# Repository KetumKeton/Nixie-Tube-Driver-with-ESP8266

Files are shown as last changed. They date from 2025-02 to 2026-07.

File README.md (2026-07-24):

<div align="right">
  <a href="README.en.md">🇬🇧 English</a> |
  <a href="README.md">🇹🇷 Türkçe</a>
</div>

# 🔥 Nixie Tube Driver with ESP8266

Wi-Fi bağlantılı, ESP8266 tabanlı Nixie tüp sürücü kartı. Nixie saat ve sayısal gösterge projeleri için tasarlanmıştır; interneti kullanarak saatini otomatik kalibre eder ve zaman bölmeli çoklama (time-division multiplexing) ile birden fazla tüpü aynı anda sürer.

<p align="center">
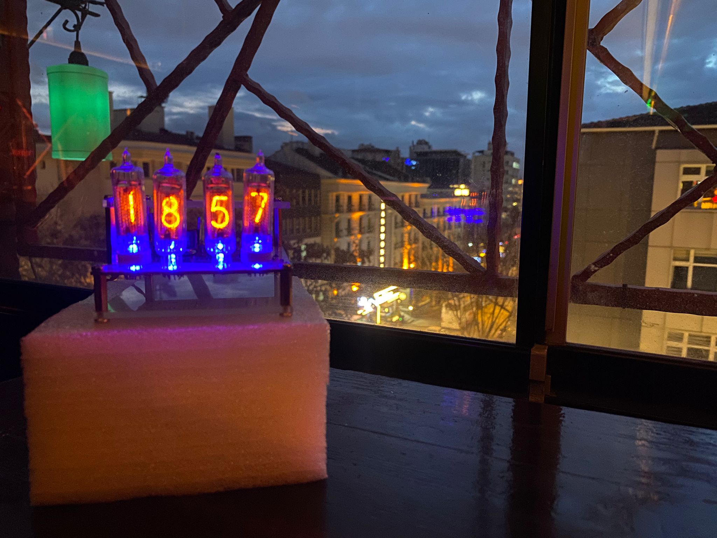
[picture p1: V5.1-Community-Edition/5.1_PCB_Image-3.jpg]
V5.2 Image
  
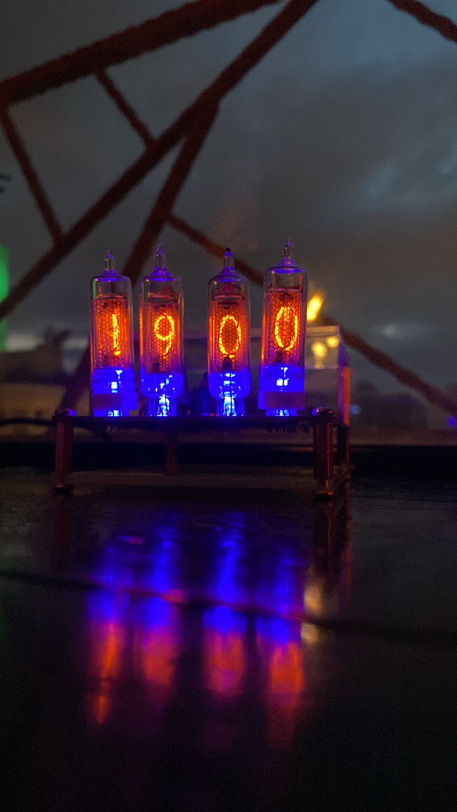
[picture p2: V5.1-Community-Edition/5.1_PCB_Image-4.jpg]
V5.2 Image
  
</p>
<p align="center">
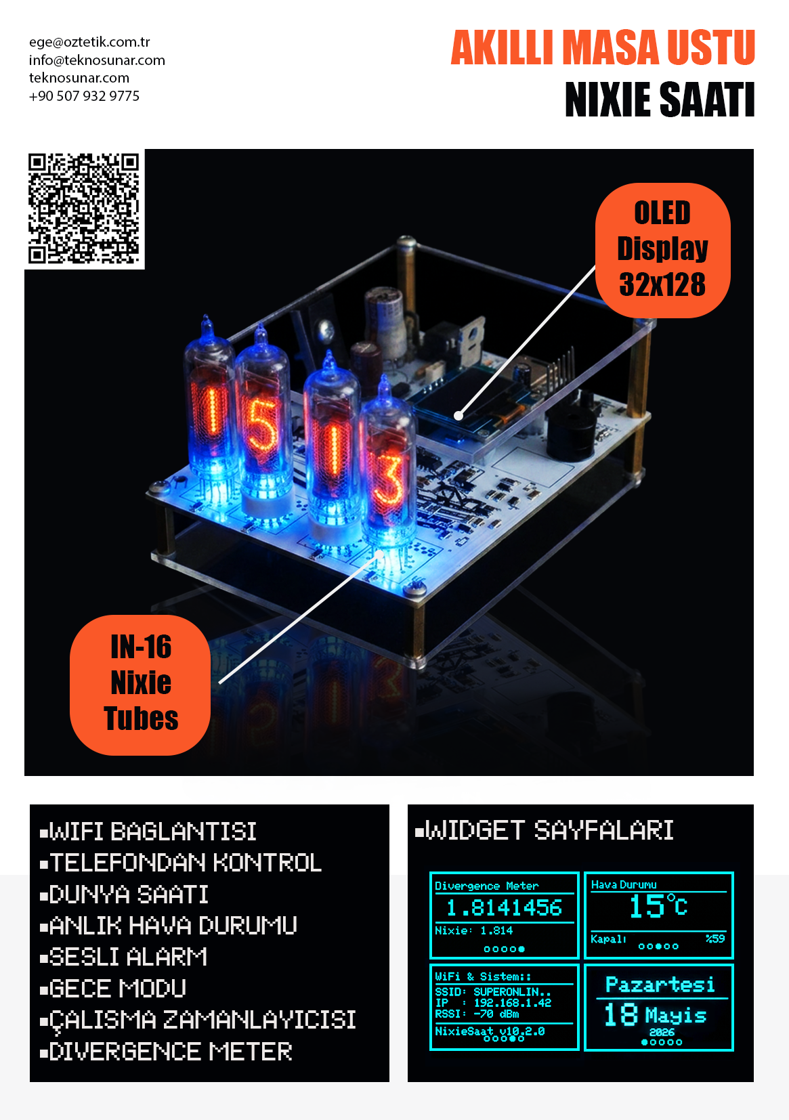
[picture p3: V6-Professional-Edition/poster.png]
    
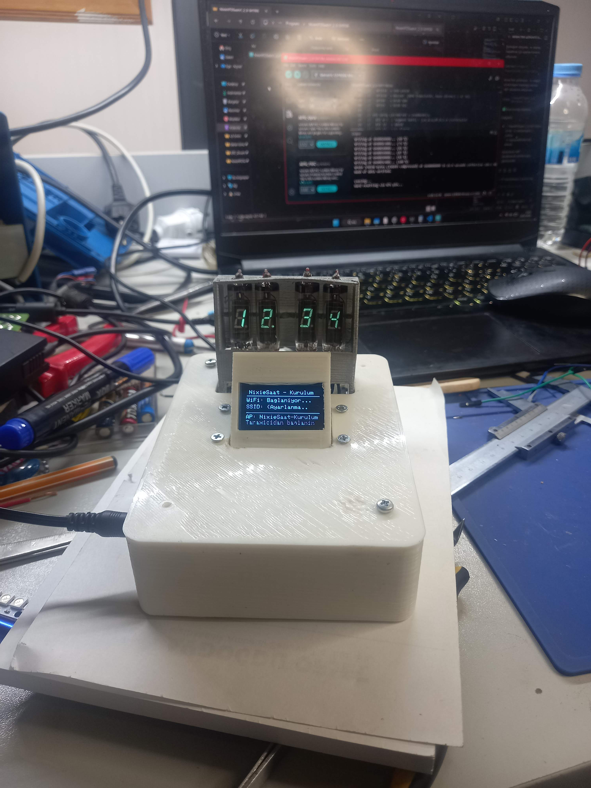
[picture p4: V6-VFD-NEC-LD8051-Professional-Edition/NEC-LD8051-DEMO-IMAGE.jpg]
V6-VFD Image
  
</p>
---

## 📖 İçindekiler

- [Proje Hakkında](#-proje-hakkında)
- [Özellikler](#-özellikler)
- [Donanım Gereksinimleri](#-donanım-gereksinimleri)
- [Kurulum ve Kullanım](#-kurulum-ve-kullanım)
- [Galeri](#-galeri)
- [Versiyon Notları](#-versiyon-notları)
- [Yol Haritası](#-yol-haritası)
- [Lisans](#-lisans)
- [Katkıda Bulunma](#-katkıda-bulunma)

---

## 🧭 Proje Hakkında

Bu proje, Nixie tüplerini (IN-16 için tasarlanmıştır, IN-12/IN-14/IN-18 gibi diğer tüplerle de uyumludur / Pro versiyonunda NEC-8051 / IV-3 VFD tüplerine uygun tasarımda bulunmaktadır) sürmek için gereken yüksek gerilim anahtarlama devresini, mikrodenetleyici firmware'ini ve PCB tasarımını bir arada sunar. Kart, ESP8266 üzerinden internete bağlanarak NTP ile saatini otomatik senkronize eder, böylece harici bir RTC pil değişimine veya manuel saat ayarına gerek kalmaz.

### Open Core - Community Edition
Açık kaynak felsefesine inandığım için, bu Nixie saatin temel versiyonunu herkesin kendi evinde yapabilmesi adına şemaları, kodları ve CAM dosyalarıyla v5.1 Comunity Edition olarak paylaşıyorum. Eğer kendi ESP8266'nızı programlamak, shift register'larla uğraşmak ve 170V DC-DC boost konvertör gibi yüksek voltajlı devreleri kendi başınıza kurmak istiyorsanız, ihtiyacınız olan her şey bu depoda mevcut!"

### Proffesional Edition
"Ancak, lehim yapmakla, parça tedarikiyle veya yüksek voltajla uğraşmak istemiyorsanız; çok daha gelişmiş bir web arayüzüne, ekstra animasyon modlarına ve kusursuz bir tasarıma sahip olan tam donanımlı versiyonu doğrudan tak-çalıştır bir ürün olarak satın almak isterseniz aşşağıdaki iletişim adresinden bana ulaşabilirsiniz.

Web Site: teknosunar.com / oztetik.com.tr
mail: info@teknosunar.com / ege@oztetik.com.tr
github: KetumKeton
linkedin: ege-oztetik

## ✨ Özellikler

**Donanım**
- 🔥 IN-16 Nixie tüpleri için optimize edilmiş sürücü devresi; diğer Nixie tipleriyle de uyumlu
- 🔄 4 tüpün aynı anda, zaman bölmeli çoklama (16 transistörlü anahtarlama) ile sürülmesi
- ⚡ Dahili MC34063 DC-DC çevirici ile 150V DC yüksek gerilim üretimi (harici trafoya gerek yok — V5 ve sonrası)
- 🔋 Düşük güç tüketimine göre optimize edilmiş anahtarlama tasarımı
- 🎨 Estetik odaklı, sıkı yerleşimli PCB tasarımı (80×100 mm, V5)
- 🖥️ İsteğe bağlı OLED ekran bağlantısı (alternatif/yardımcı çıkış)
- 🟦 Nixie tüpleri için mavi arka plan LED desteği

**Yazılım / Firmware**
- 📶 ESP8266 üzerinden otomatik Wi-Fi bağlantısı
- 🕒 İnternet üzerinden NTP ile gerçek zamanlı saat kalibrasyonu
- 💡 Ayarlanabilir parlaklık ve yumuşak geçiş/söndürme (fade) efektleri
- 🔌 Seri haberleşme desteği (test ve yapılandırma için)
- 🧩 CD4094 kaydırma yazmaçları üzerinden basamak sürme

## 🛠 Donanım Gereksinimleri

| Bileşen | Not |
|---|---|
| Mikrodenetleyici | ESP8266 (ESP-12) |
| Nixie Tüpleri | IN-16 için tasarlandı (IN-12, IN-14, IN-18 ile de uyumlu) |
| Yüksek Gerilim Kaynağı | 150V DC (V5'te kart üzerinde MC34063 ile üretilir) |
| Sürücü IC | CD4094 (kaydırma yazmacı), ULN2003 (küçük SMD versiyonda) |

## 🚀 Kurulum ve Kullanım

1. **Depoyu klonlayın**
   ```sh
   git clone https://github.com/Ketonkeko/Nixie-Tube-Driver-with-ESP8266.git
   cd Nixie-Tube-Driver-with-ESP8266
   ```

2. **Gerber dosyalarını üretim için alın**
   - İlgili versiyon klasöründeki zip dosyasını açın; içinden drill ve copper Gerber dosyalarını çıkarıp PCB üreticinize gönderin.

3. **Firmware'i yükleyin**
   - İlgili versiyon klasöründeki Arduino/ESP8266 projesini açın.
   - Wi-Fi ağı bilgilerinizi kod içinde ilgili değişkenlere girin.
   - Kartı USB-seri dönüştürücü ile bağlayıp firmware'i ESP8266'ya yükleyin.

4. **İlk çalıştırma**
   - Kart açıldığında tanımlı Wi-Fi ağına bağlanır ve NTP sunucusundan saati çeker.
   - Yüksek gerilim beslemesini (150V) ve tüp soketlerini bağlamadan önce devrenin güç kesici olduğundan emin olun.

> ⚠️ **Güvenlik uyarısı:** Bu kart 150V DC gibi tehlikeli seviyede yüksek gerilimle çalışır. Kartı yalnızca yüksek gerilim devreleriyle çalışma tecrübeniz varsa enerjilendirin.

## 🖼 Galeri

<table>
  <tr>
    <td align="center">
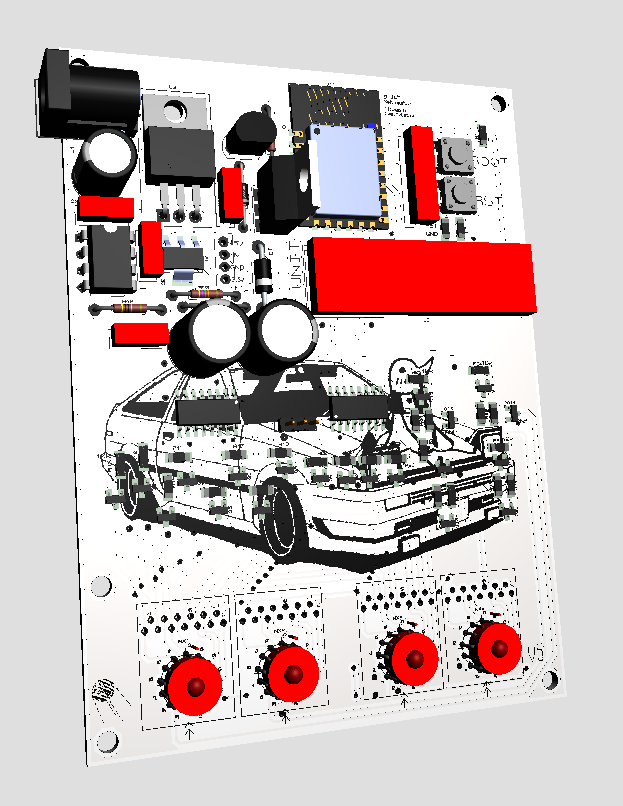
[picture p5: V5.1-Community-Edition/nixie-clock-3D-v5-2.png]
V5.2 3D Görünüm
      <br>
      <sub>V5.2 — 3D model</sub>
    </td>
    <td align="center">
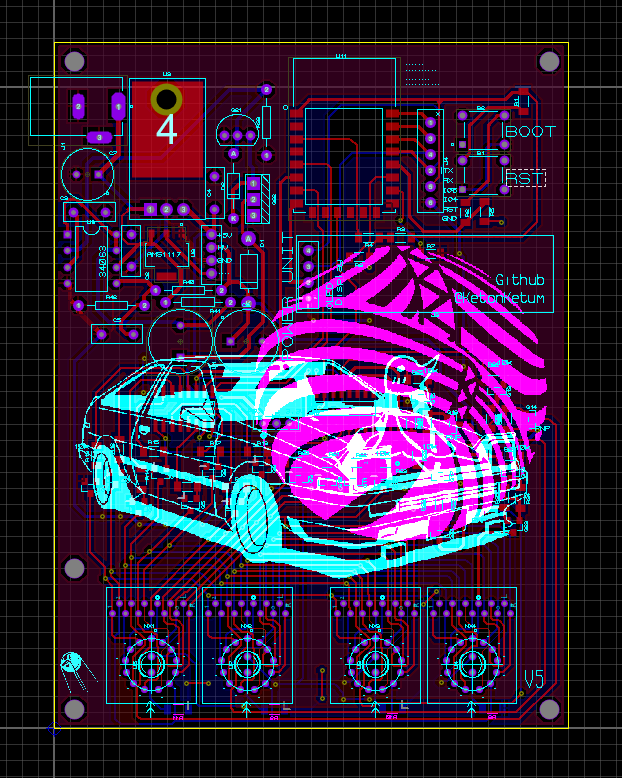
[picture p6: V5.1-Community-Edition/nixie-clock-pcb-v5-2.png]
V5.2 PCB Görünümü
      <br>
      <sub>V5.2 — PCB düzeni</sub>
    </td>
  </tr>
  <tr>
    <td align="center">
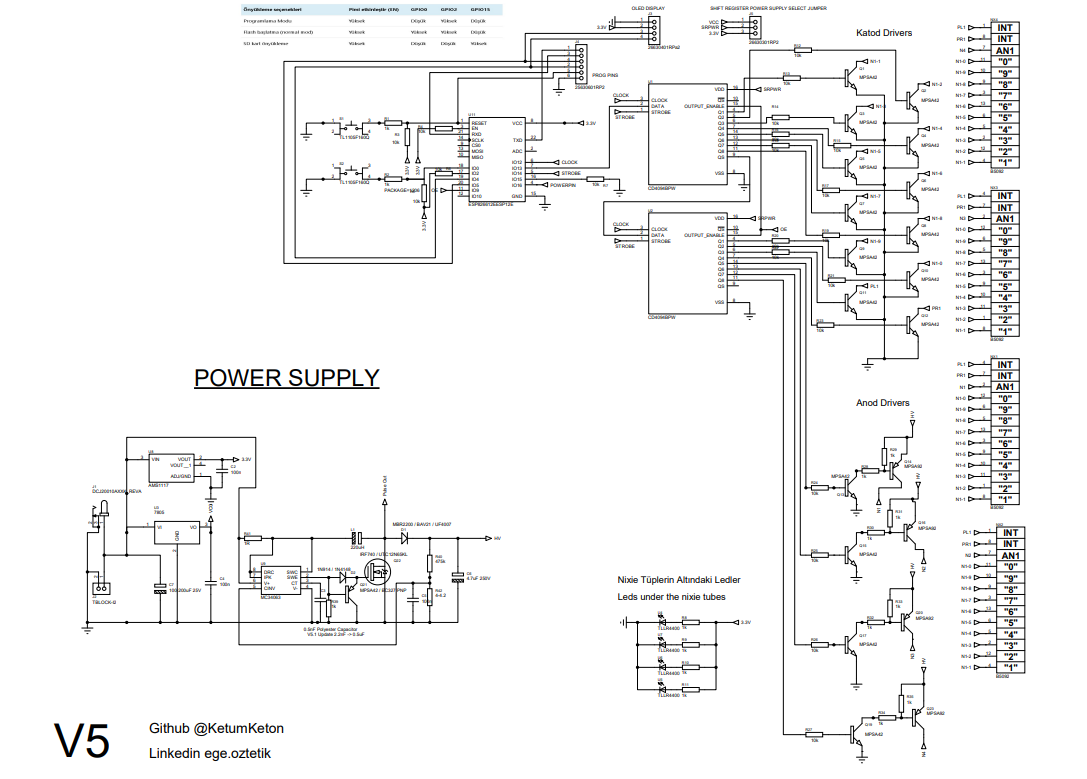
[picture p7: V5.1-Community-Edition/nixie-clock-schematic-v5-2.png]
V5.2 Şematik
      <br>
      <sub>V5.2 — Şematik</sub>
    </td>
    <td align="center">
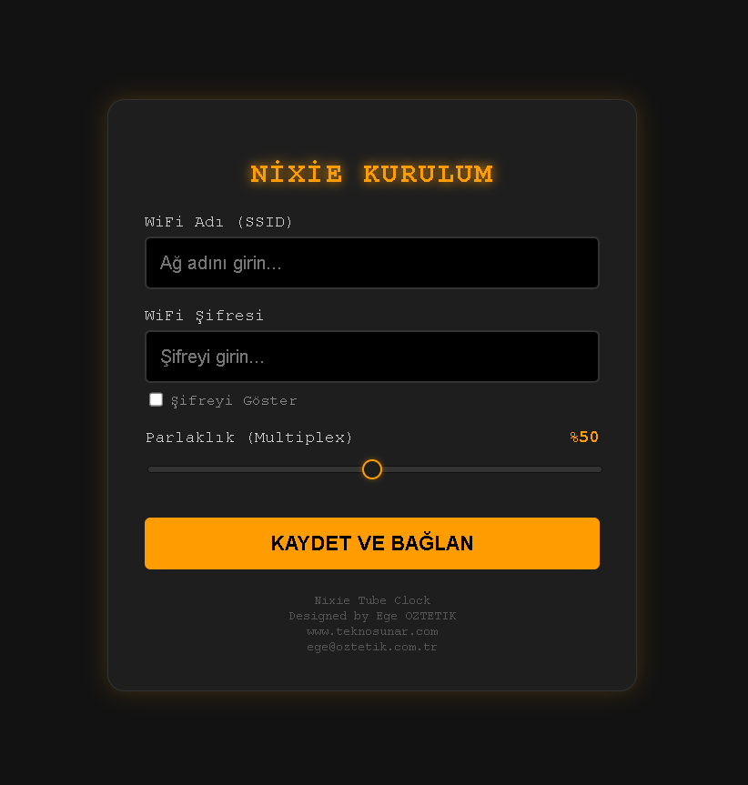
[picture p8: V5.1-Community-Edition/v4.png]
V4 Uygulama Görseli
      <br>
      <sub>V4 — Örnek uygulama</sub>
    </td>
  </tr>
  <tr>
    <td align="center">
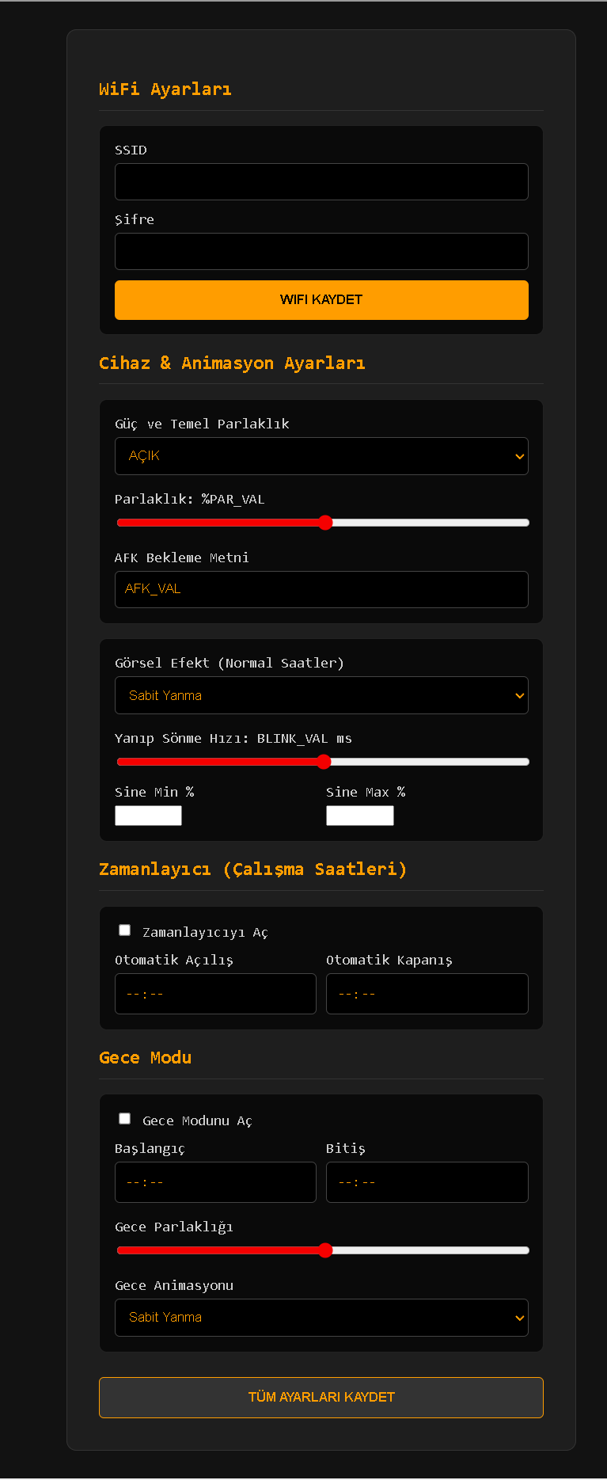
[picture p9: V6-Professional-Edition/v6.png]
V6 Uygulama Görseli
      <br>
      <sub>V6 — Örnek uygulama</sub>
    </td>
    <td align="center">
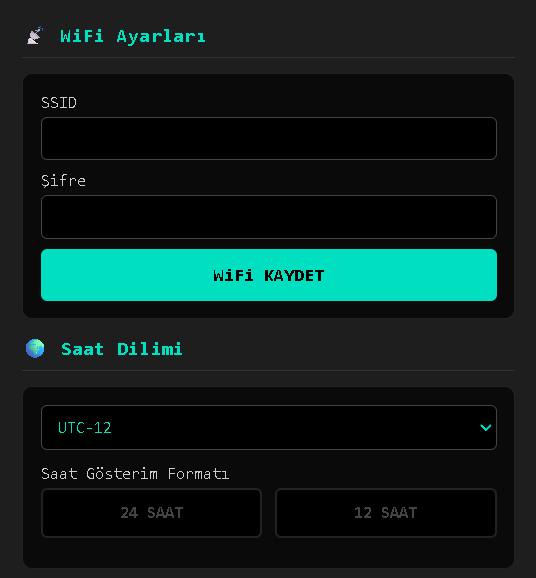
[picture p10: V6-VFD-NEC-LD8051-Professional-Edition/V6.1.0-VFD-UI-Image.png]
V6 VFD Test
      <br>
      <sub>V6 — NEC LD8051 VFD test</sub>
    </td>
  </tr>
    <tr>
    <td align="center">
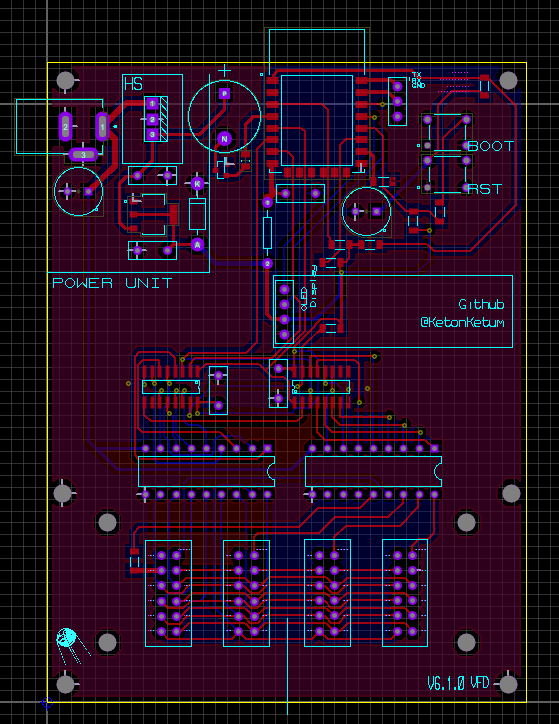
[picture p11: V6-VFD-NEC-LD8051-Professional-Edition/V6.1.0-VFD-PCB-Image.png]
      <br>
      <sub>V6 — Örnek uygulama</sub>
    </td>
    <td align="center">
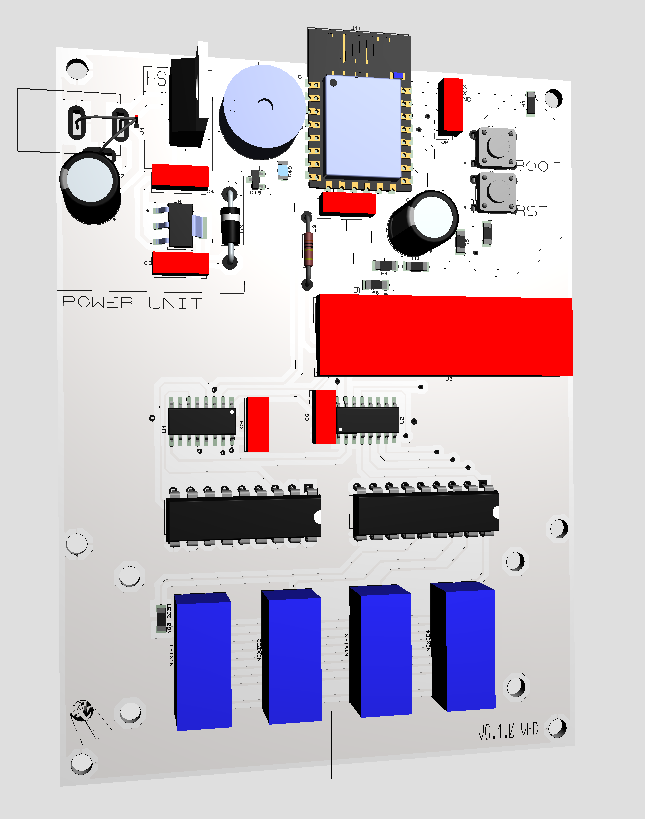
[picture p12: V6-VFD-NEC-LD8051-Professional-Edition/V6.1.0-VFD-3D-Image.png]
      <br>
      <sub>V6 — NEC LD8051 VFD test</sub>
    </td>
  </tr>
    <tr>
    <td align="center">
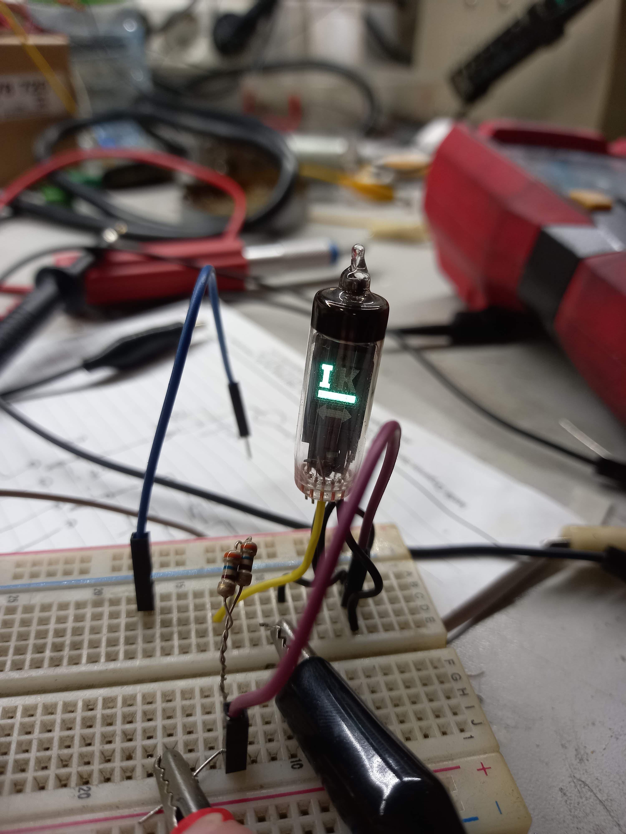
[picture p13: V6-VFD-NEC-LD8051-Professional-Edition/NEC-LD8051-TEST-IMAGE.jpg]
      <br>
      <sub>V6 — Örnek uygulama</sub>
    </td>
    <td align="center">
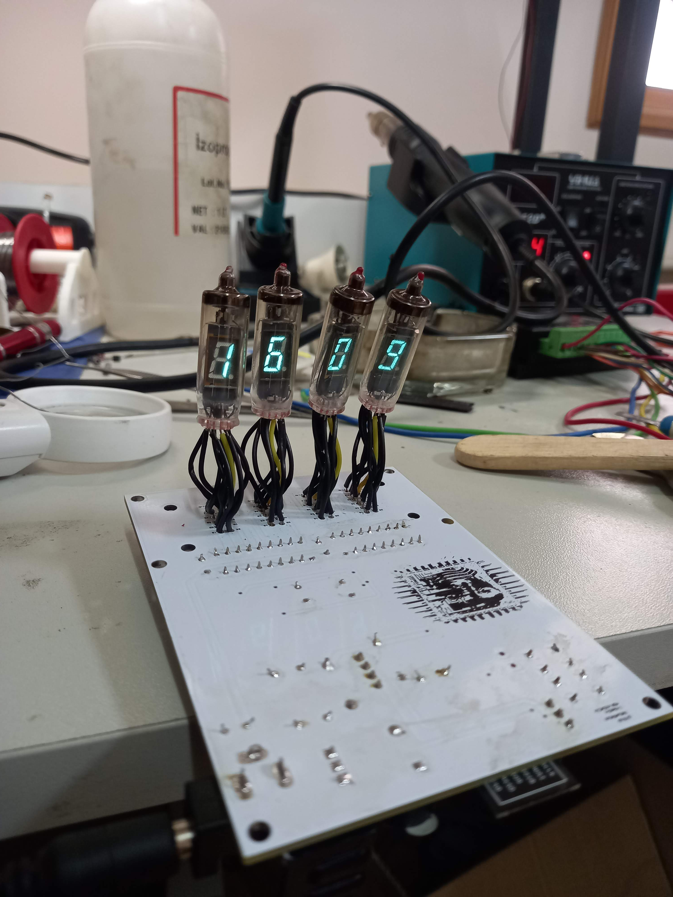
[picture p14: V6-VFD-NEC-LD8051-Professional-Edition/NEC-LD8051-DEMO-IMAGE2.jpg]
      <br>
      <sub>V6 — NEC LD8051 VFD test</sub>
    </td>
  </tr>
</table>

## 🗂 Versiyon Notları

### V6 — VFD Desteği
- NEC LD8051 VFD (vakum floresan gösterge) ile deneysel test desteği eklendi.
- UI VFD Tüplere Göre Güncellendi
- Dış Kasa Tasarlandı (oled ve VFD tüleri için soket tasarımı dahil)
- Kontrol Şeması 7 segment olucak şekilde yeniden yazıldı ve program güncellendi

### V6 Notları
- Program Güncellemeleri Yapıldı ve Yeni Özellikler Eklendi v10-3 (Alarm, Çalışma Zamanlayıcısı, Gece Modu, Effektler, Yakınsama Sayısı Modu, Saat Gösterim Şekilleri ve Yerel Zaman Seçenekleri vs)
- Koruma Elemanları ve Bleeder direnci Eklendi 
- Tasarım Değişiklikleri Yapıldı ve Çalışma daha Stabil Hale getirildi
- Tüplerin Çalışma Ömrünü uzatmak amacıyla Katot koruması vb koruma özellikleri eklendi

### V5 Notları
- Harici trafo yerine dahili MC34063 DC-DC çeviricisi entegre edildi.
- Anot sürücüsündeki hata giderildi.
- Güç filtrelemesi için ek kapasitörler eklendi.
- Güç girişlerine dahili diyotlar eklendi.
- PCB, 80×100 mm ölçüsünde yeniden çizildi.
- CD4094, SO16 paketine geçirildi.
- Bazı hatlar kalınlaştırıldı.
- Pin header boyutları güncellendi.
- 402 paket kapasitörler 603'e dönüştürüldü.
- OLED ekran daha görünür bir konuma taşındı.
- Nixie mavi LED dirençleri 1206 pakete dönüştürüldü.
- Nixie tüp soket boyutu güncellendi.

### V4 Notları
- Mikrodenetleyici AT89C4051'den ESP8266'ya değiştirildi.
- RS485 haberleşmesi kaldırılıp Wi-Fi eklendi.
- 16 transistörlü zaman bölmeli çoklama ile 4 tüpün eşzamanlı sürülmesi sağlandı.
- Daha iyi PCB tasarımı için bitmap desteği eklendi.
- Üretim ve boyut iyileştirmesi için paket DIP'ten SMD'ye değiştirildi.
- HV ve 12V girişleri harici güç kaynağına (trafo) bağlandı.
- Alternatif çıkış seçeneği olarak OLED ekran pinleri eklendi.

## 🗺 Yol Haritası

- [x] ESP8266 E-12 ile saat programının yazılması
- [x] SMD ve ULN2003 IC ile daha küçük PCB tasarımı
- [x] Saat için 3D kasa tasarımı
- [x] PCB ve program testleri
- [x] Parça listesi ve maliyet hesaplaması
- [X] ESP8266 üzerinde yerel sunucu ile alarm ve saat dilimi ayarı
- [X] UI İyileştirmeleri
- [ ] Çeşitli Dış Kasa Tasarımları Yapılıcak
- [ ] RTC Eklenecek
- [ ] 6 Tüplü Versiyon Tasarlanacak
- [ ] Pleksi-Ledli Versiyon Tasarlanacak

## 📜 Lisans

Bu proje **MIT Lisansı** ile lisanslanmıştır. Ayrıntılar için [LICENSE](LICENSE) dosyasına bakın.

## 🤝 Katkıda Bulunma

Katkılarınızı bekliyoruz! **Pull request** gönderebilir veya **issue** açabilirsiniz.

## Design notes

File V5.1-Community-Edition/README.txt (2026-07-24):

# Open-Core - Community Edition
Açık kaynak felsefesine inandığım için, bu Nixie saatin temel versiyonunu herkesin kendi evinde yapabilmesi adına şemaları, kodları ve CAM dosyalarıyla v5.1 Community Edition olarak paylaşıyorum. Eğer kendi ESP8266'nızı programlamak, shift register'larla uğraşmak ve 170V DC-DC boost konvertör gibi yüksek voltajlı devreleri kendi başınıza kurmak istiyorsanız, ihtiyacınız olan her şey bu depoda mevcut!

# Professional Edition
Ancak, lehim yapmakla, parça tedarikiyle veya yüksek voltajla uğraşmak istemiyorsanız; çok daha gelişmiş bir web arayüzüne, ekstra animasyon modlarına ve kusursuz bir tasarıma sahip olan tam donanımlı versiyonu doğrudan tak-çalıştır bir ürün olarak satın almak isterseniz aşağıdaki iletişim adreslerinden bana ulaşabilirsiniz.

Web Site: teknosunar.com / oztetik.com.tr
mail: info@teknosunar.com / ege@oztetik.com.tr
github: KetumKeton
linkedin: ege-oztetik

# Open-Core - Community Edition
As a believer in the open-source philosophy, I am sharing the schematics, source codes, and CAM files of this Nixie clock's basic version as the v5.1 Community Edition, so anyone can build it at home. If you want to program your own ESP8266, tinker with shift registers, and build high-voltage circuits like a 170V DC-DC boost converter yourself, everything you need is right here in this repository!

# Professional Edition
However, if you'd rather not deal with soldering, sourcing components, or handling high voltages; and would prefer a fully equipped, plug-and-play product featuring a much more advanced web interface, extra animation modes, and a flawless design, you can contact me via the channels below to purchase one.

Web Site: teknosunar.com / oztetik.com.tr
mail: info@teknosunar.com / ege@oztetik.com.tr
github: KetumKeton
linkedin: ege-oztetik

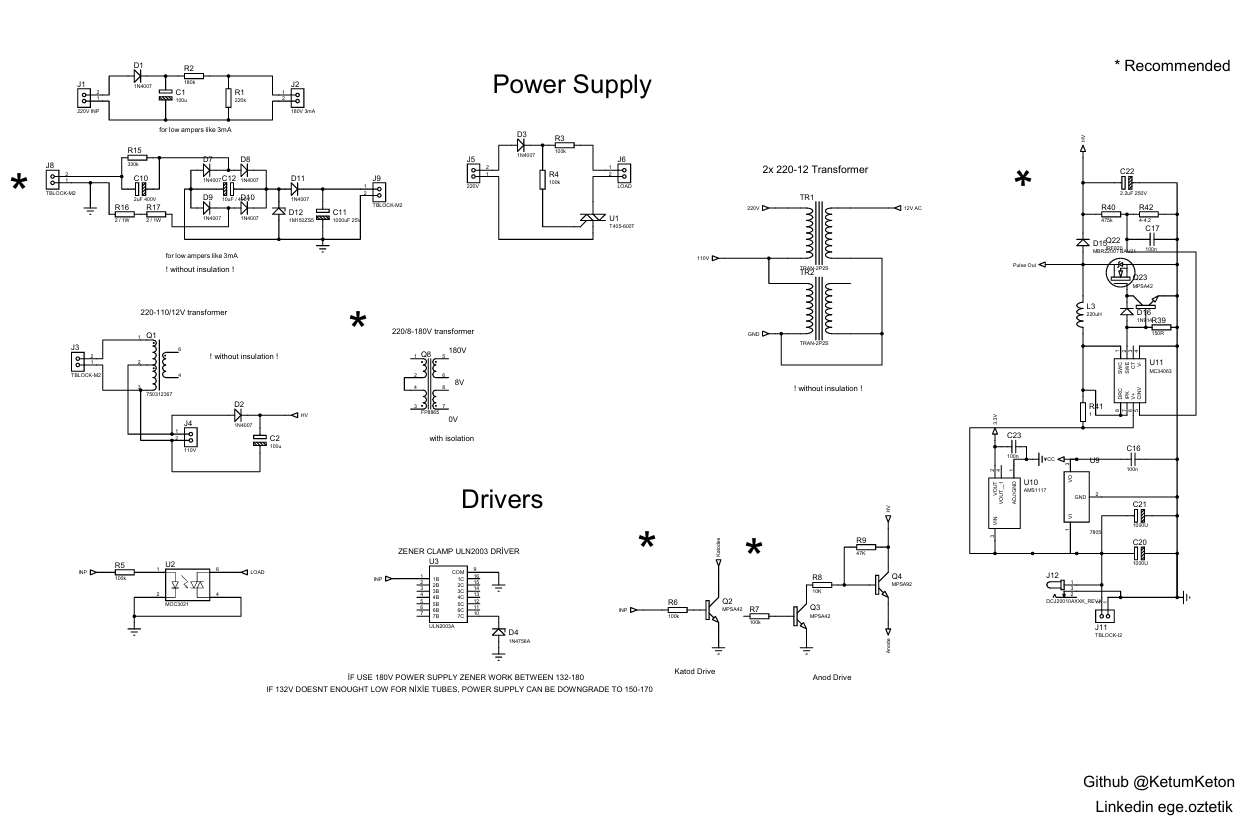
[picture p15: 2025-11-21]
power-supply-and-driver-schematic.png

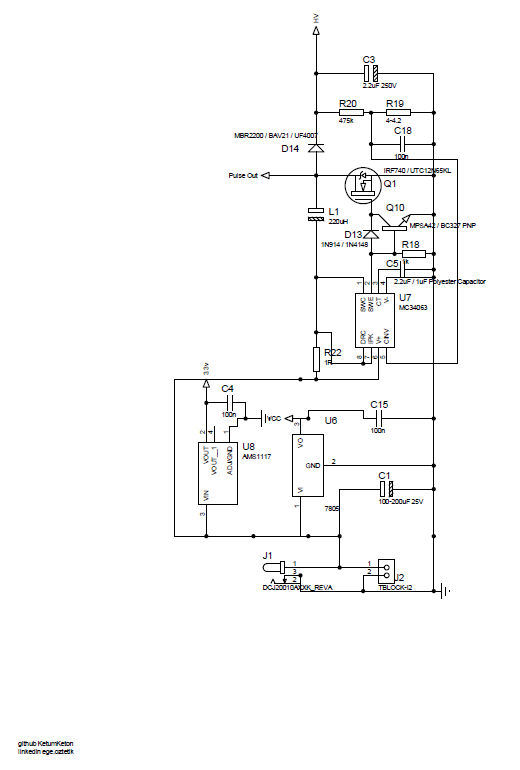
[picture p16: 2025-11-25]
V5.1-Community-Edition/HV-Power-Supply/12V-HV-V1-2-schematic.png

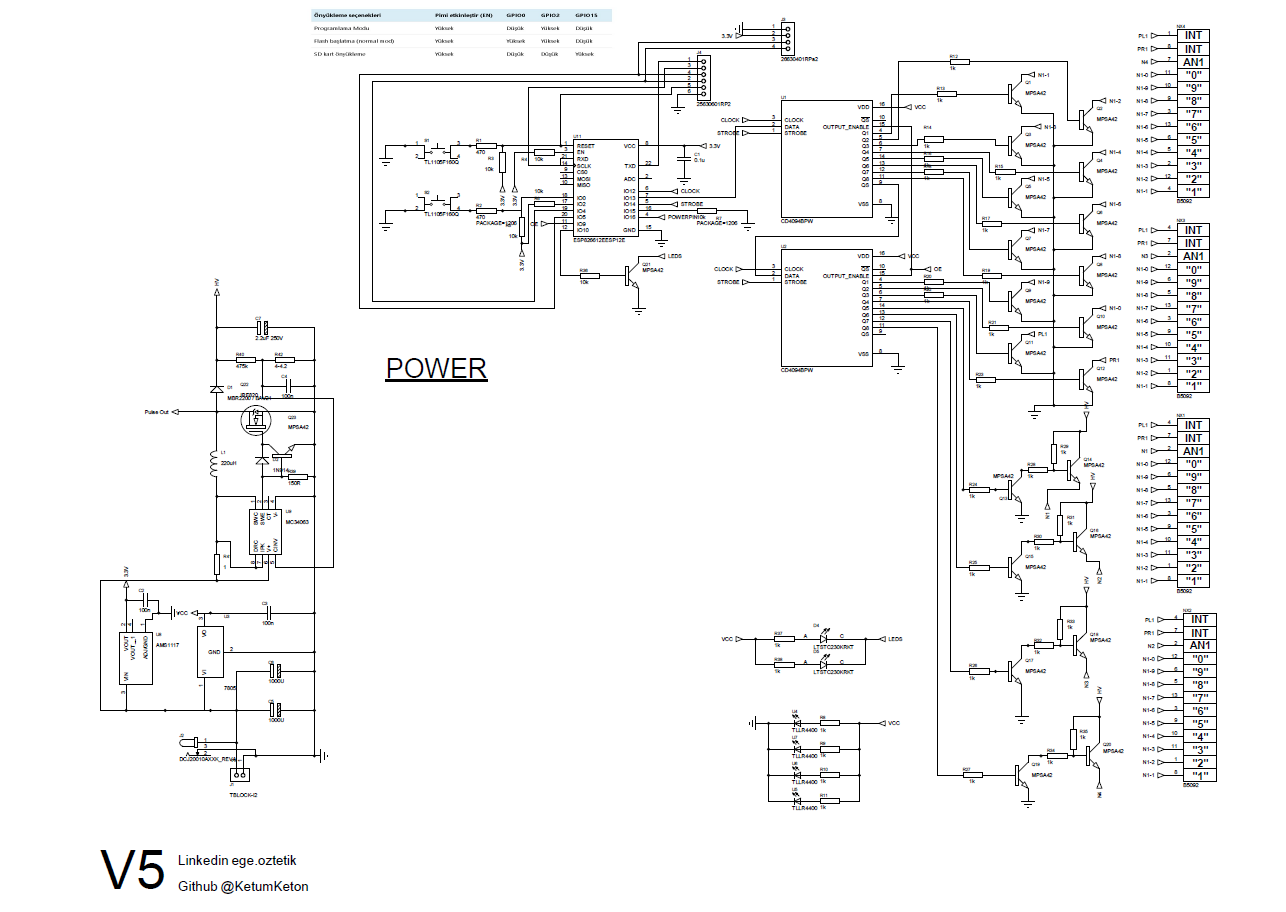
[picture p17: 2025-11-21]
V5.1-Community-Edition/5.1/nixie-clock-schematic-v5-1.png

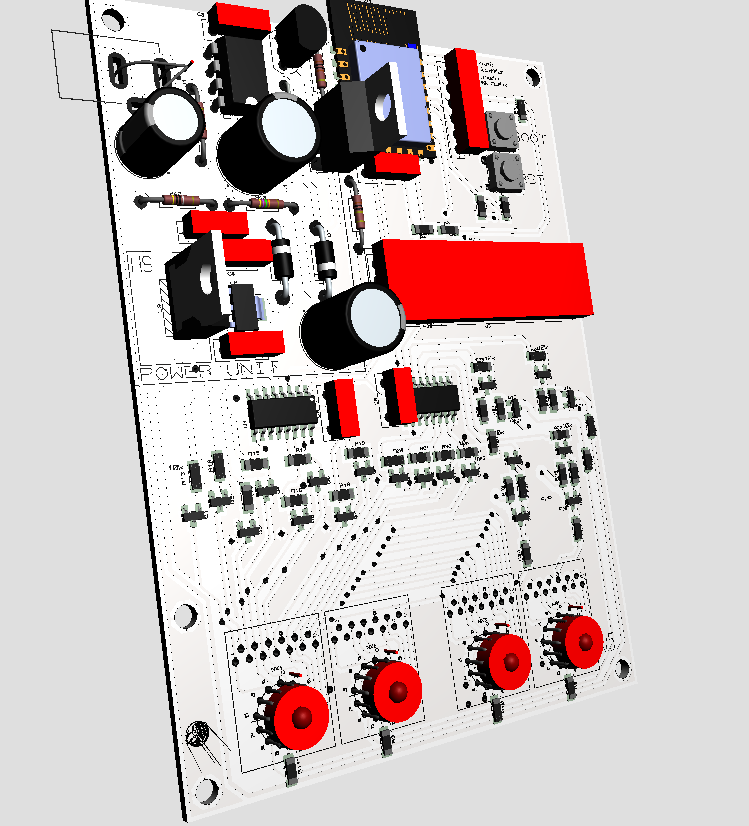
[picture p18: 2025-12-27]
V6-Professional-Edition/NixieClock-V6-3D.png

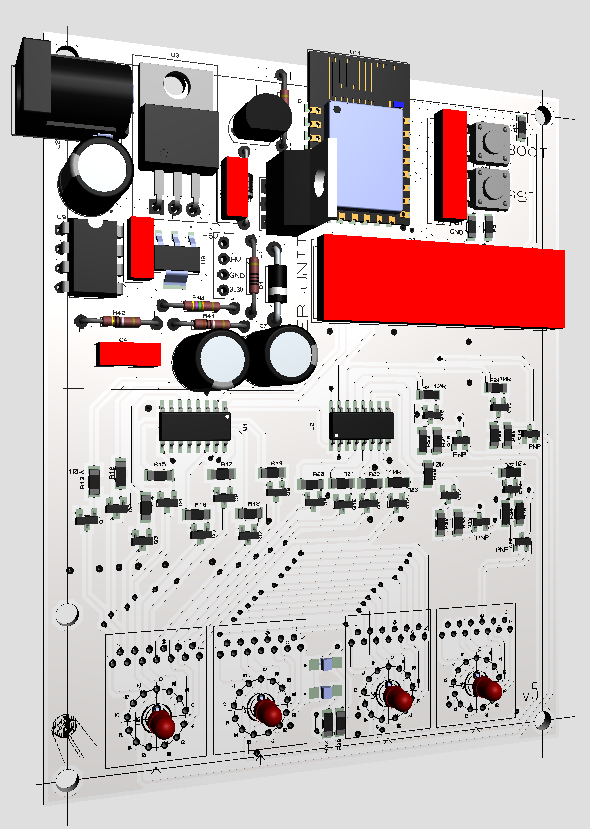
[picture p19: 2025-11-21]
V5.1-Community-Edition/5.1/nixie-clock-3D-v5-1.png

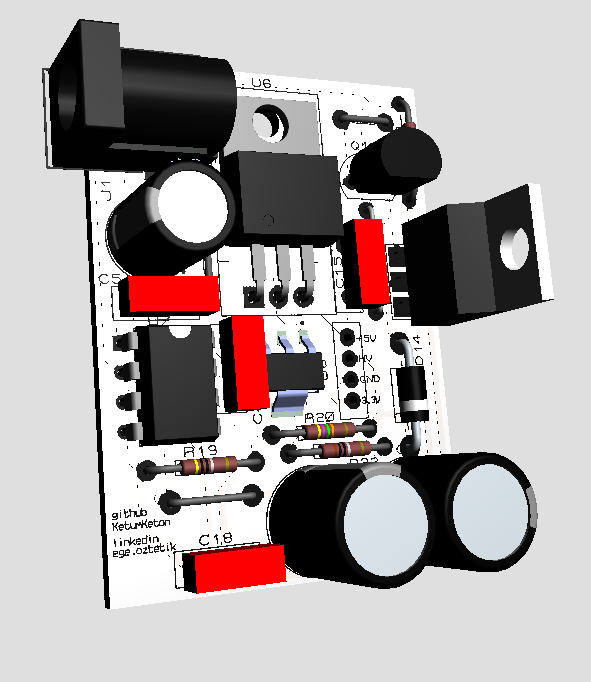
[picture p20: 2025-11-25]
V5.1-Community-Edition/HV-Power-Supply/12V-HV-V1-2-3D.png

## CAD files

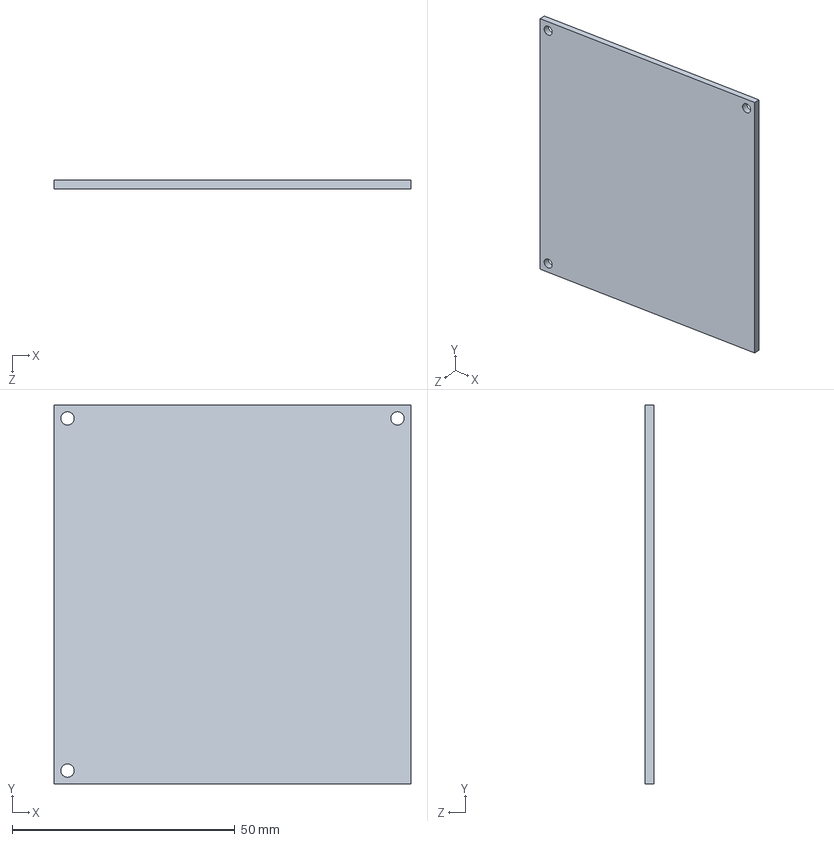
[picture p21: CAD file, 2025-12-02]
V5.1-Community-Edition/ust-parca.SLDPRT
80.0 x 85.0 x 2.00 mm

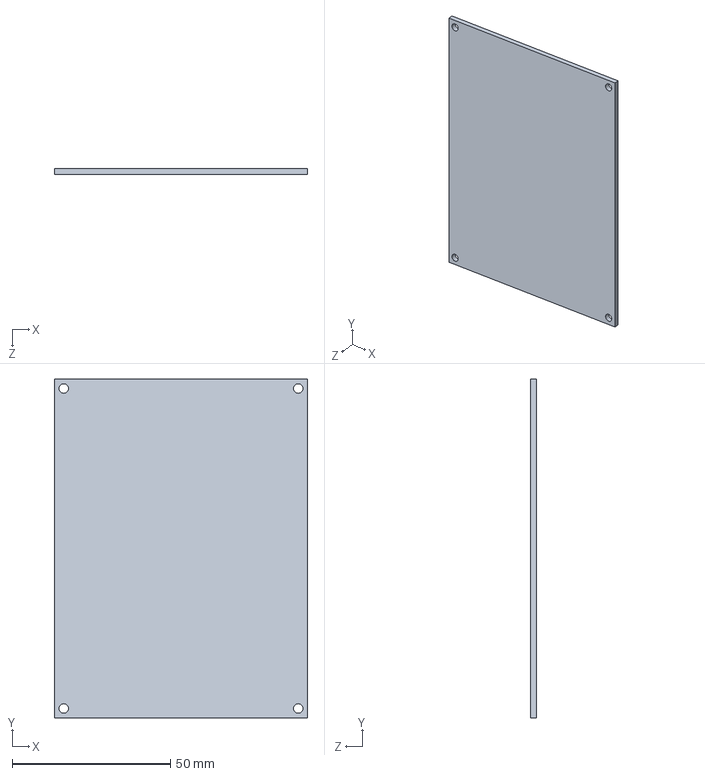
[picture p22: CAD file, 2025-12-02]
V5.1-Community-Edition/alt-parca.SLDPRT
80.0 x 107.0 x 2.00 mm

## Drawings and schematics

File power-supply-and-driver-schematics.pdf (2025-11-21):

J1

D1

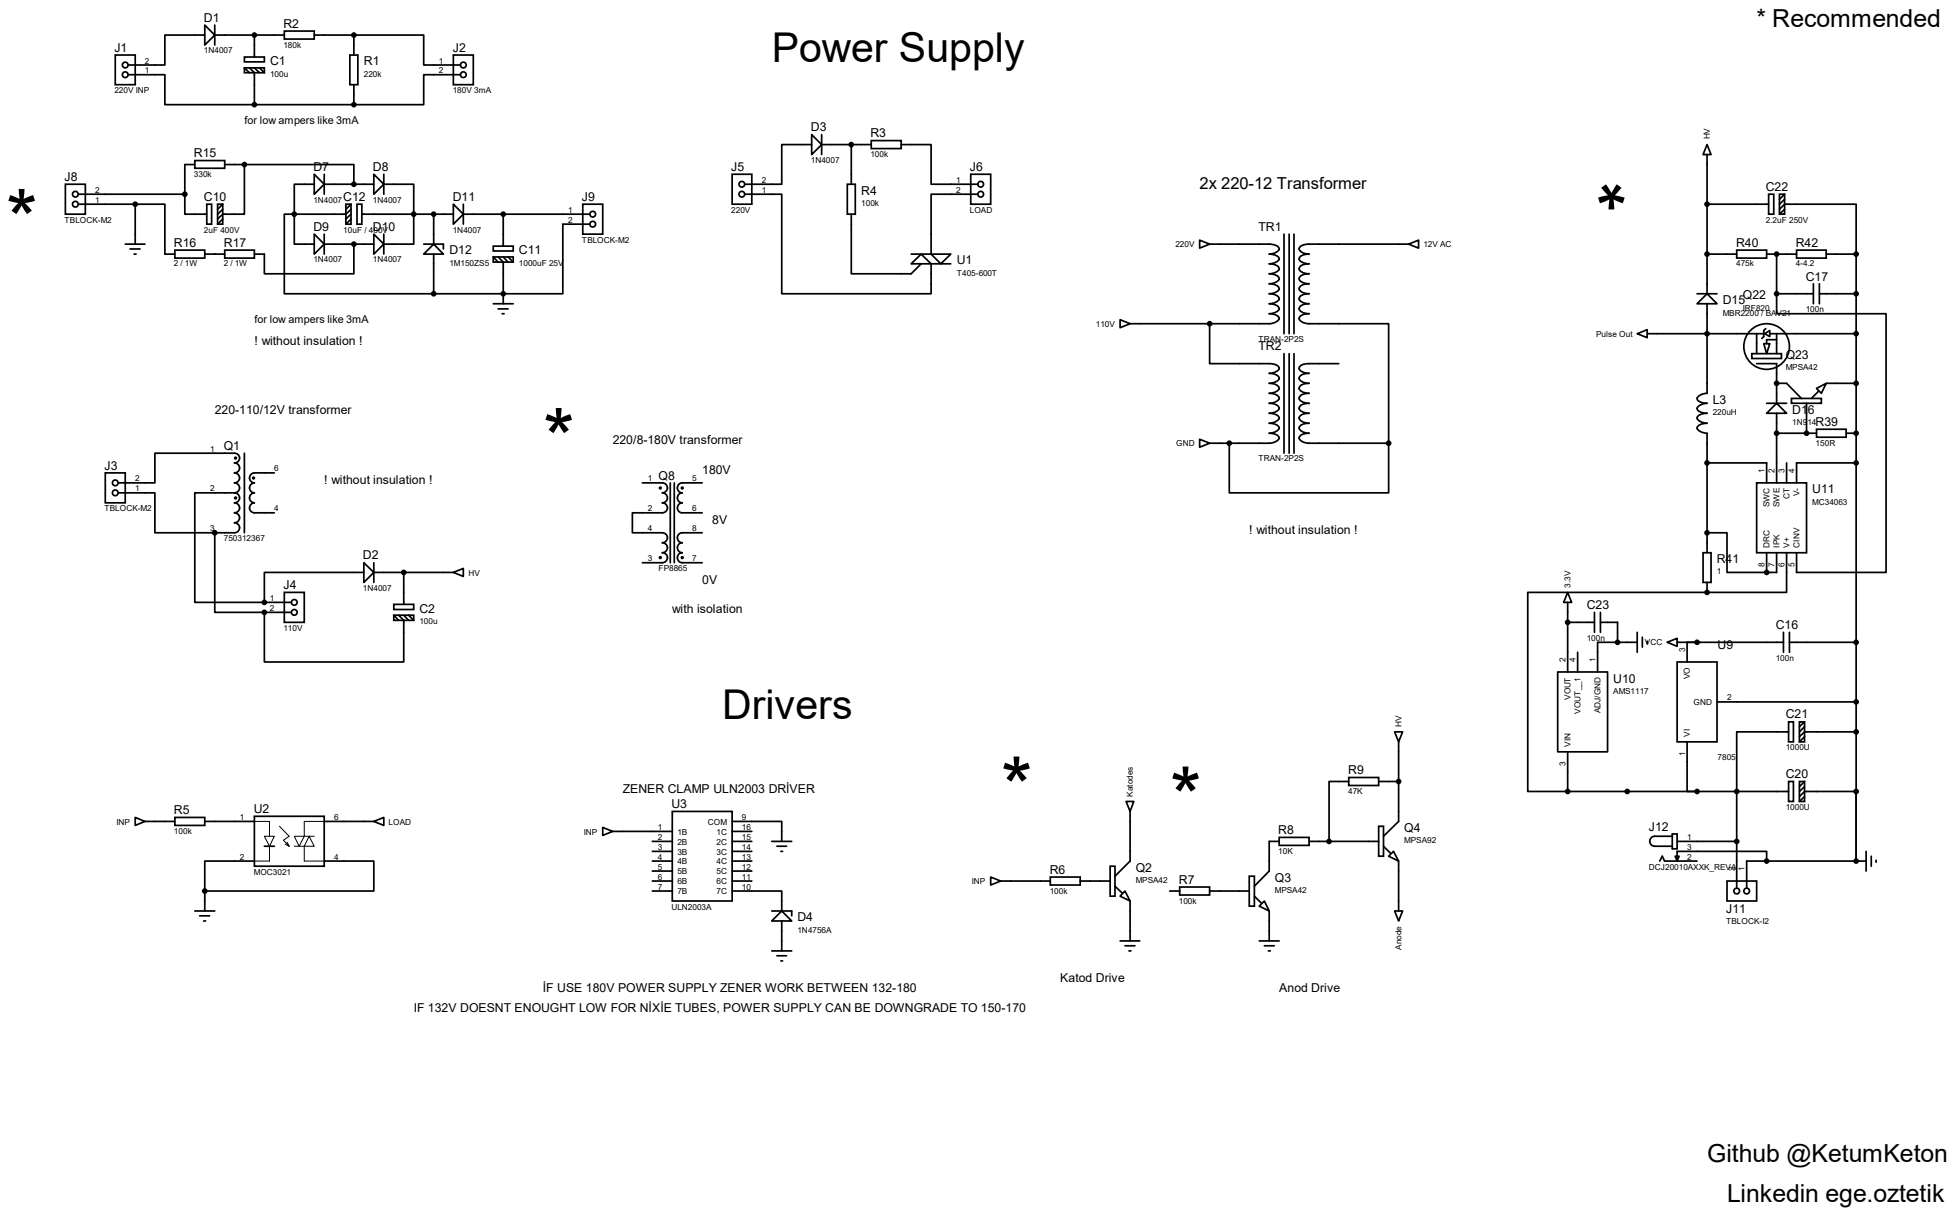
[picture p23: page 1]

for low ampers like 3mA

! without insulation !

İF USE 180V POWER SUPPLY ZENER WORK BETWEEN 132-180

IF 132V DOESNT ENOUGHT LOW FOR NİXİE TUBES, POWER SUPPLY CAN BE DOWNGRADE TO 150-170

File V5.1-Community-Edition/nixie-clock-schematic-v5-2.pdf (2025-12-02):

10k 3.3V

# INT

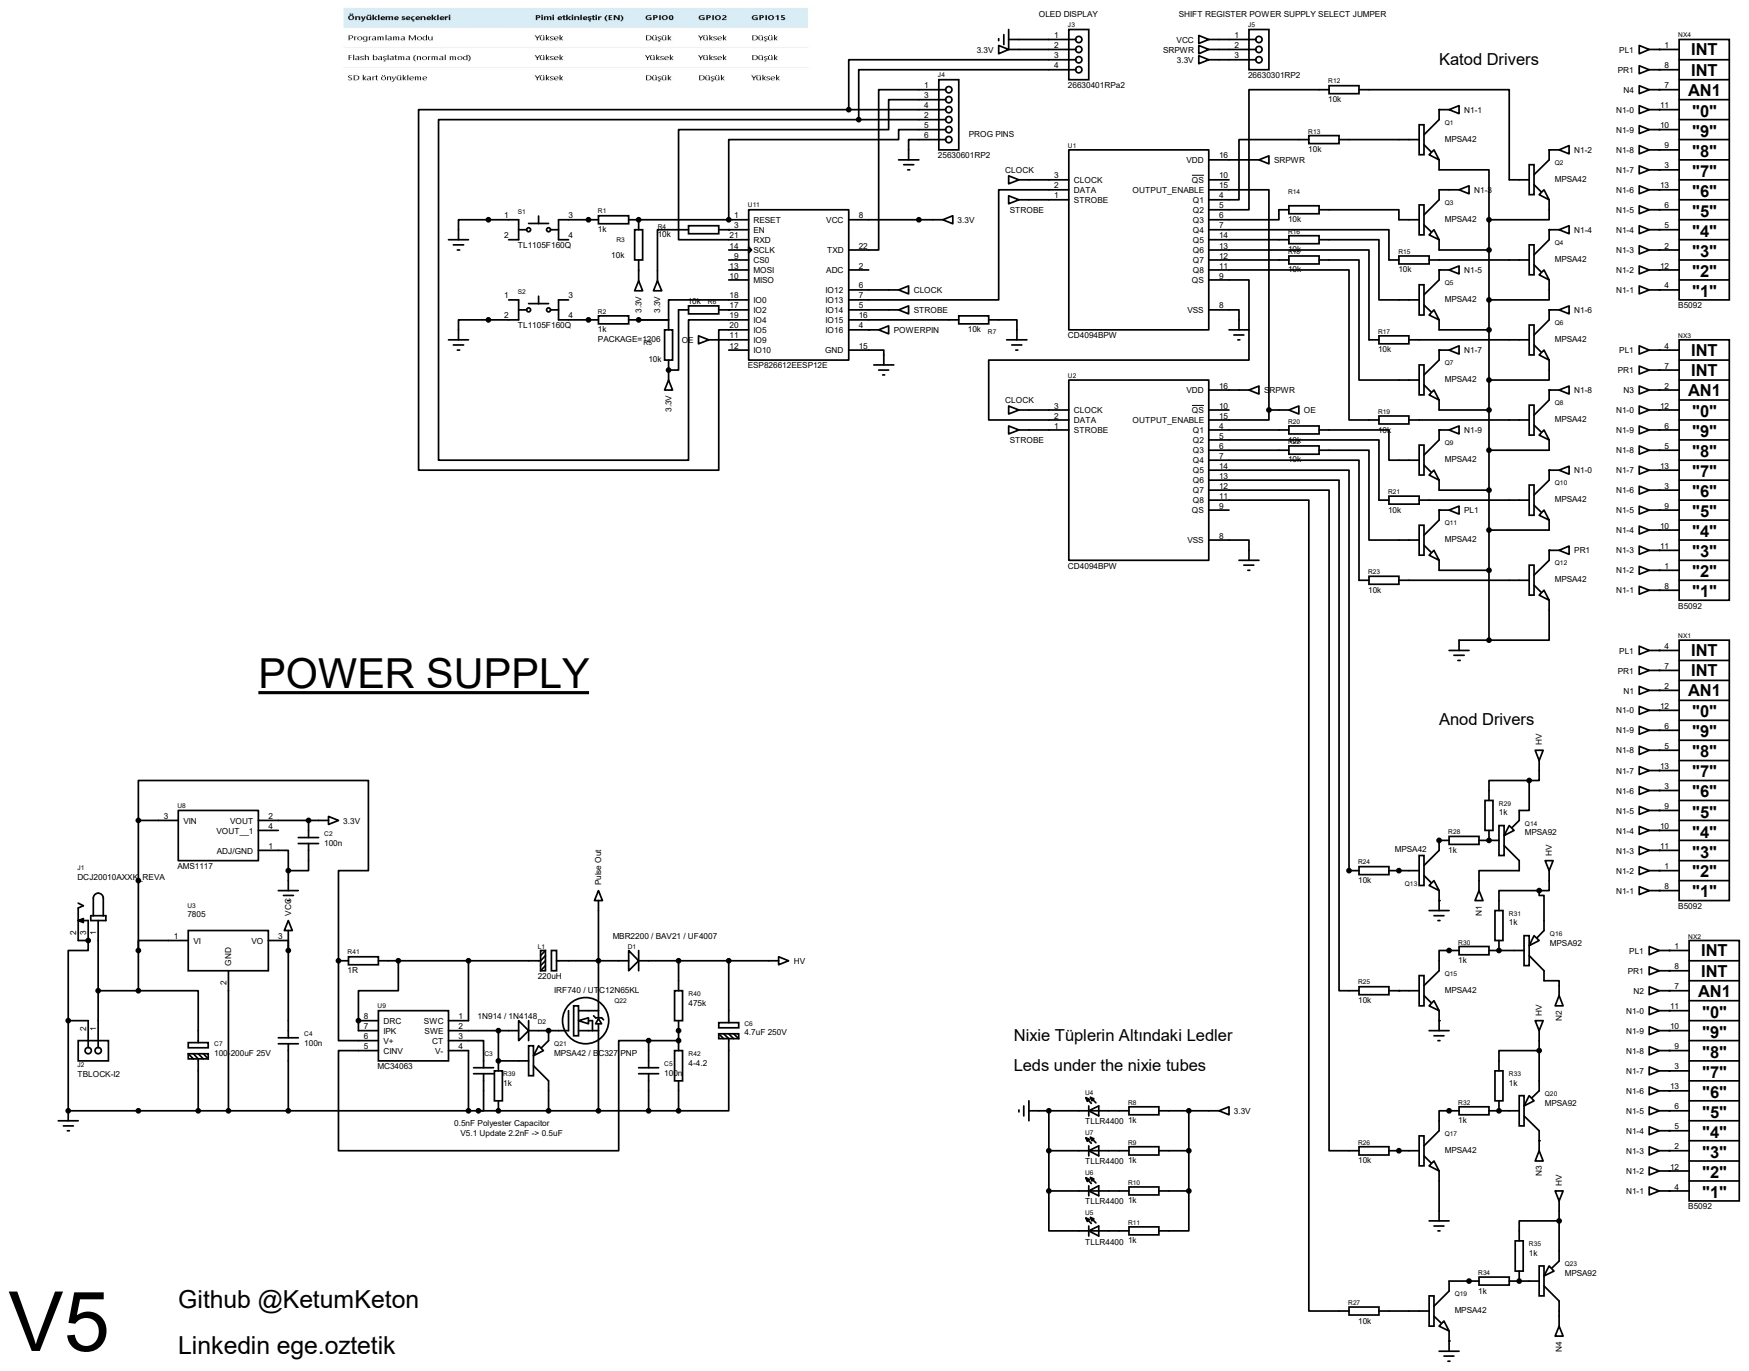
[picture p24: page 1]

SHIFT REGISTER POWER SUPPLY SELECT JUMPER

Nixie Tüplerin Altındaki Ledler
Leds under the nixie tubes

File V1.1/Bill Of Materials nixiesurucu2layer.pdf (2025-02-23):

## Bill Of Materials for nixiesurucu2layer

Design Title | | nixiesurucu2layer

### Author Document Number Revision

Design Created | 4 Şubat 2025 Salı

### Design Last Modified 23 Şubat 2025 Pazar Total Parts In Design 83

0 Modules
Quantity | References | Value | Stock Code | Unit Cost
Sub-totals: | | | | ₺0,00
10 Capacitors
Quantity | References | Value | Stock Code | Unit Cost
2 | C1,C10 | 10u | Digikey P966-ND
2 | C2-C3 | 100u 25V | Digikey P966-ND
5 | C4-C5,C7-C9 | 100n | Maplin BX76H
1 | C6 | 470p | Maplin BX76H
Sub-totals: | | | | ₺0,00
33 Resistors
Quantity | References | Value | Stock Code | Unit Cost
1 | R1 | 100k | Digikey RT0805FRE07100KL-ND
1 | R2 | 150R | M100K
3 | R3-R4,R9 | 100k | M100K
1 | R5 | 5k6 | M100K
1 | R6 | 820k | M100K
1 | R7 | 470K | M100K
1 | R8 | 47K | M100K
22 | R10-R29,R31,R33 | 10K | Digikey 311-510KFCT-ND
2 | R30,R32 | 510K | Digikey 311-510KFCT-ND
Sub-totals: | | | | ₺0,00
8 Integrated Circuits
Quantity | References | Value | Stock Code | Unit Cost
2 | U1,U3 | 4028
1 | U2 | AT89C4051
1 | U4 | 7805
1 | U5 | MC34063
1 | U6 | DS1307
1 | U7 | SMTU2032LF
1 | U8 | MAX485
Sub-totals: | | | | ₺0,00
23 Transistors
Quantity | References | Value | Stock Code | Unit Cost
1 | Q1 | IRF820
2 | Q2-Q3 | MPSA42
20 | Q4-Q12,Q22-Q32 | MPSA43
Sub-totals: | | | | ₺0,00
2 Diodes
Quantity | References | Value | Stock Code | Unit Cost
1 | D1 | 1N4007
1 | D2 | MBR2200
Sub-totals: | | | | ₺0,00
7 Miscellaneous
Quantity | References | Value | Stock Code | Unit Cost

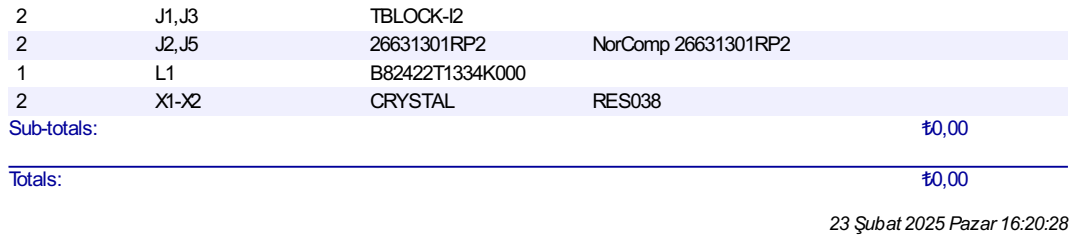
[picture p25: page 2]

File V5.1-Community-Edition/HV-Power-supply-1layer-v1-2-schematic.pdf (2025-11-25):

C18

R20

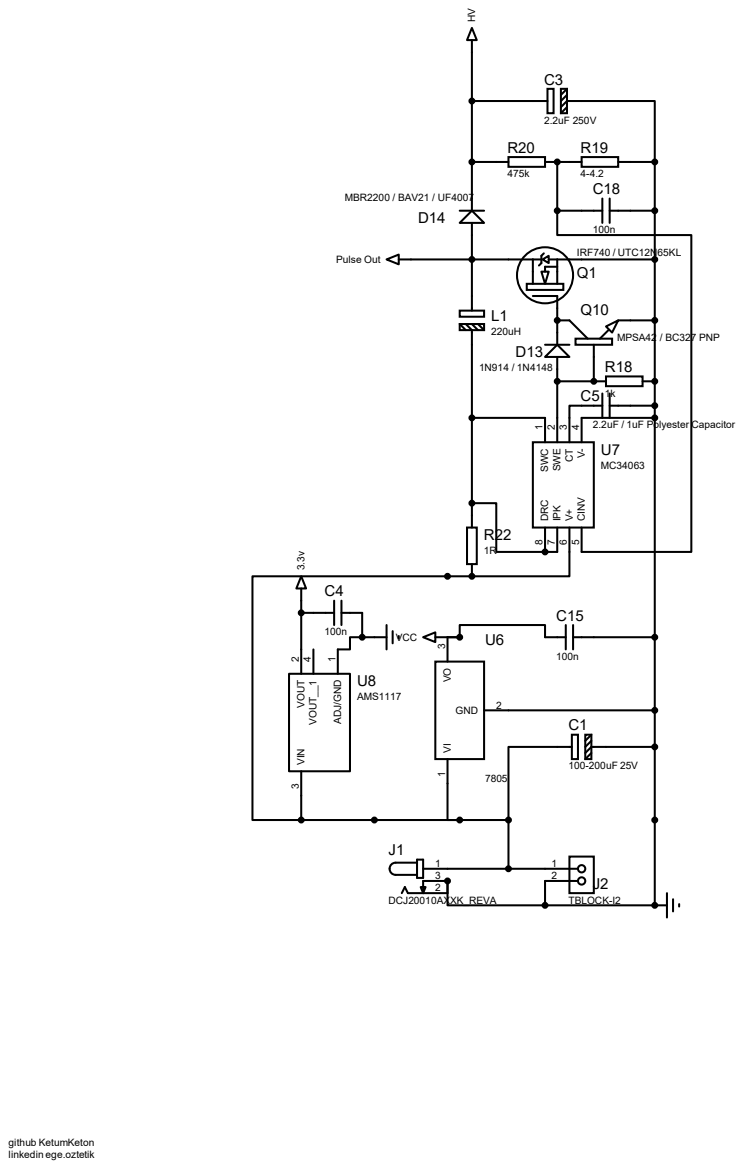
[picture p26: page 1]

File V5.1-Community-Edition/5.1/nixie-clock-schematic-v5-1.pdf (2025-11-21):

# INT

"1"

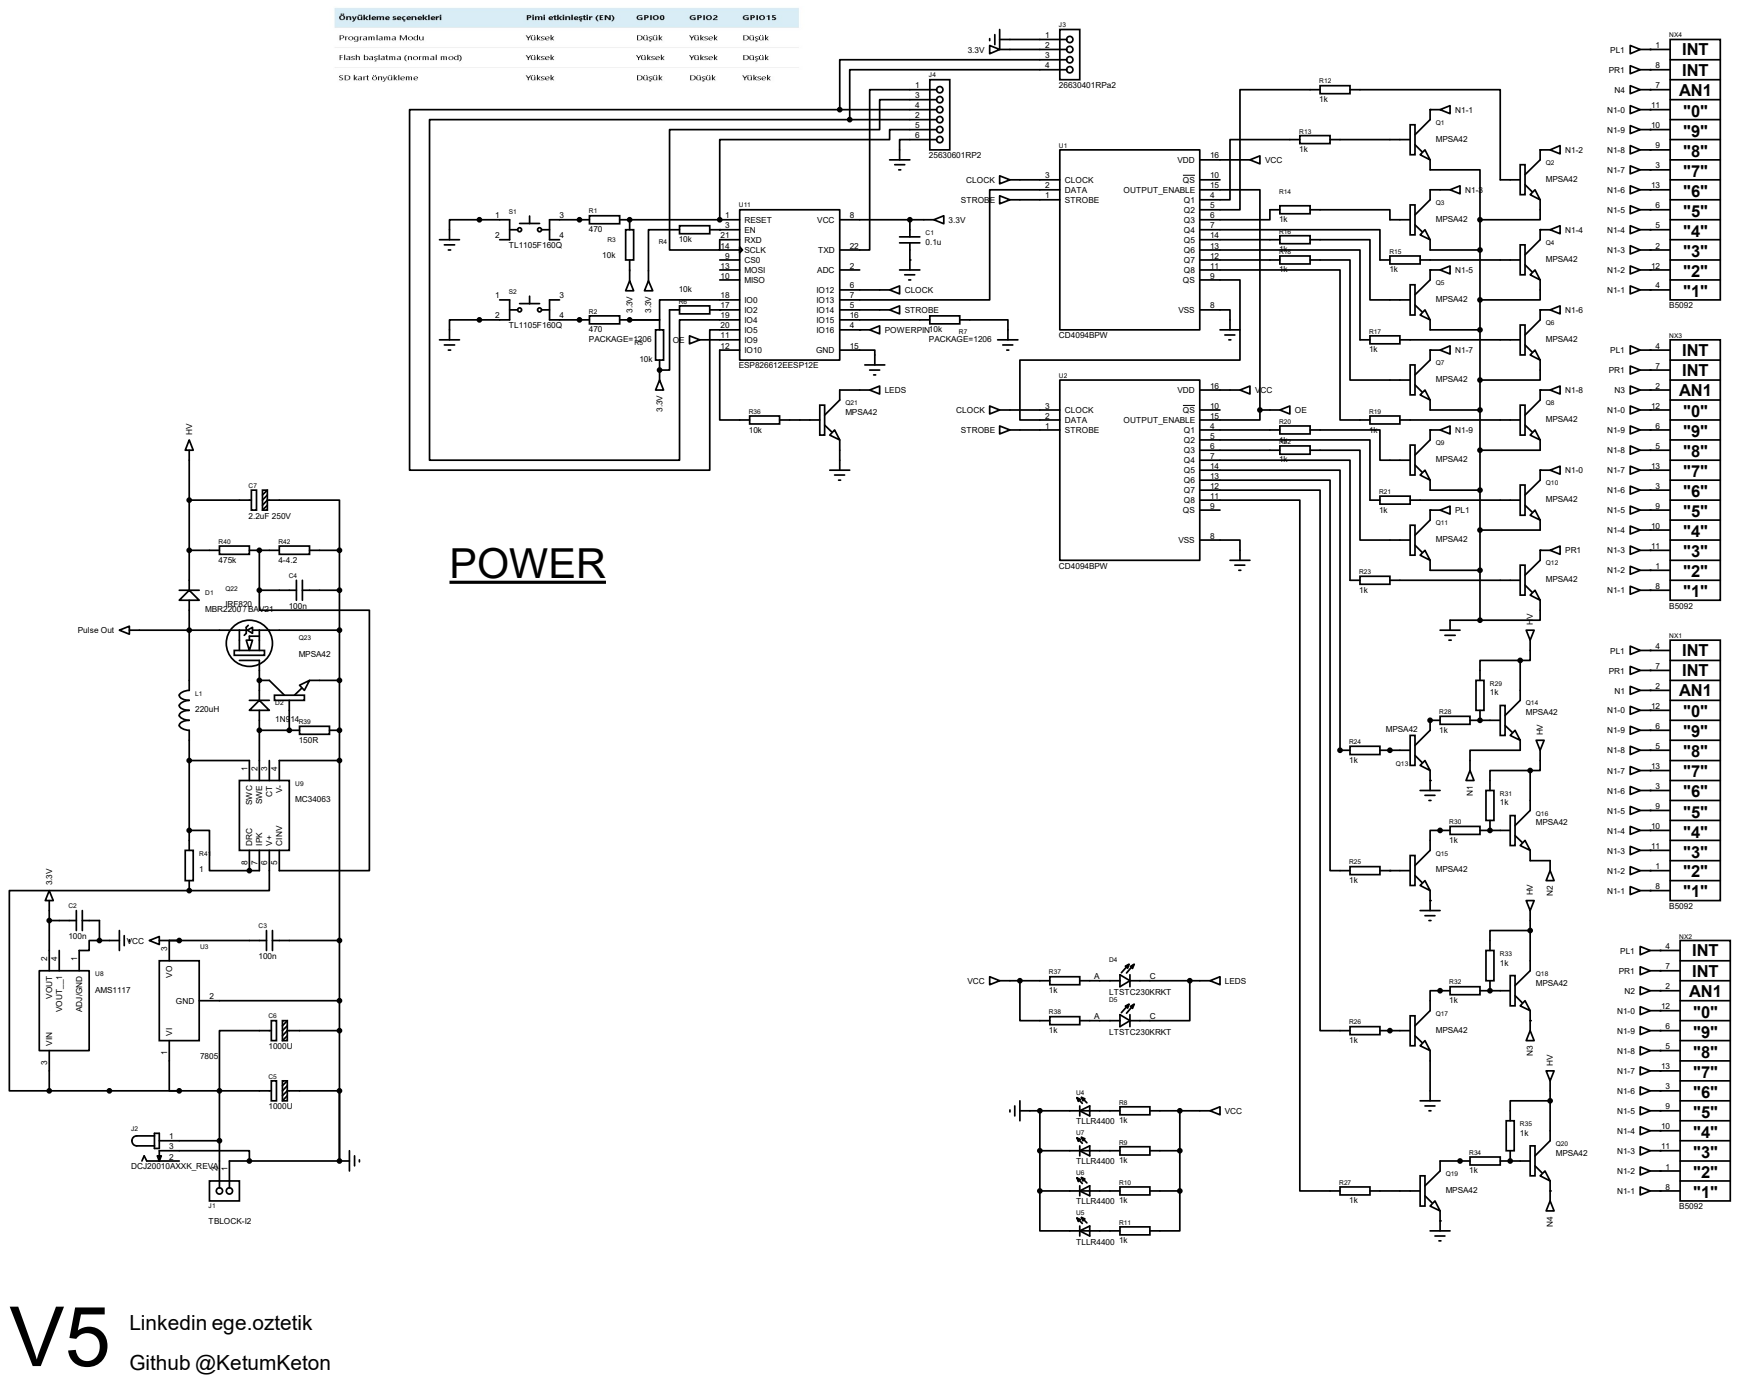
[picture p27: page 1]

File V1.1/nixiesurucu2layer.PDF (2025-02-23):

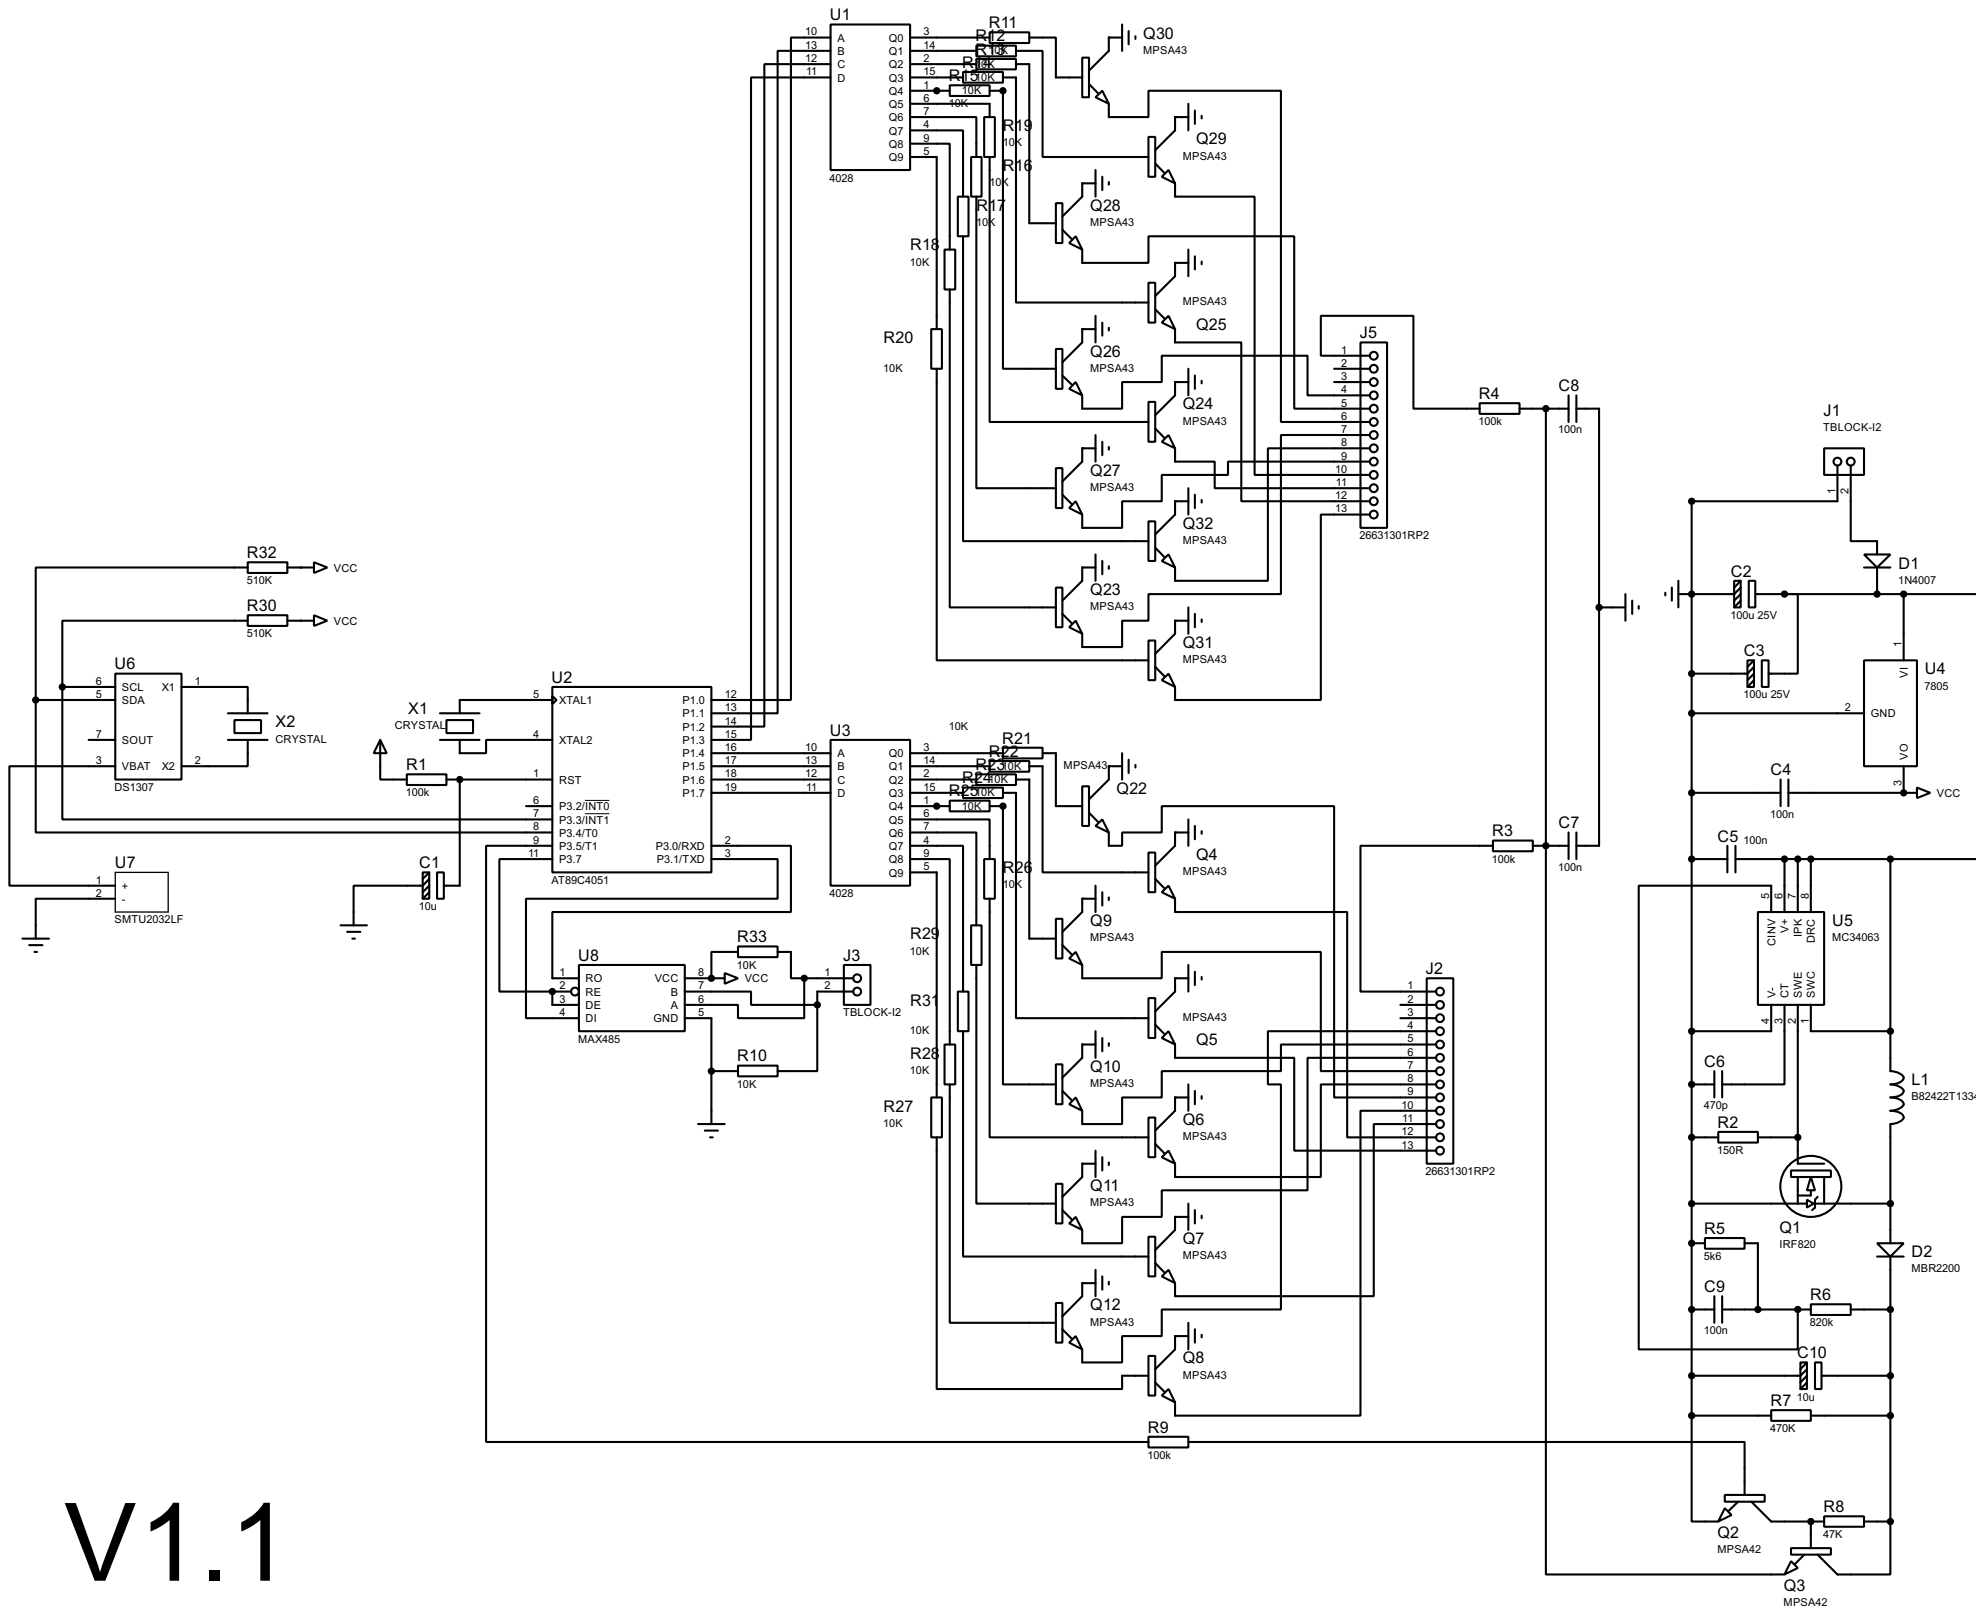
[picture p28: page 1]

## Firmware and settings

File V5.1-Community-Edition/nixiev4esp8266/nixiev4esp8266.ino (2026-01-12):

#include <ESP8266WiFi.h>
#include <WiFiUdp.h>
#include <NTPClient.h>

// ====== WiFi ======
const char* ssid     = "WIFI_ADINIZ";
const char* password = "WIFI_SIFRENIZ";

// ====== NTP (Türkiye UTC+3, yaz-kış sabit) ======
WiFiUDP ntpUDP;
NTPClient timeClient(ntpUDP, "pool.ntp.org", 3*3600, 60*1000);

// ====== 4094 Sinyalleri ======
#define PIN_DATA   13   // SER
#define PIN_CLK    12   // SRCLK
#define PIN_LATCH  14   // RCLK (STROBE)
//#define PIN_OE     9   // /OE (LOW=enable). Blanking için kullanacağız.

const bool INVERT_KATOT = false;  // katot sürücü lojik ters ise true yap
const bool INVERT_ANOT  = false;  // anot sürücü lojik ters ise true yap
const bool INVERT_DOT   = false;  // noktalar ters lojikse true

// ====== Multiplex zamanlama ======
const uint16_t ON_US_PER_TUBE = 2000;  // her tüpe ~2ms
// 4 tüp -> ~8ms frame -> ~125Hz per-tube refresh (flicker yok)

// ====== Bit Dizilimi (LSB->MSB sırayla kaydırılacak 16 bit frame) ======
// Bit 0..8  : digit 1..9 katotları
// Bit 9     : digit 0 katodu
// Bit 10    : sol nokta
// Bit 11    : sağ nokta
// Bit 12..15: Anot seçimi (4 tüp)
enum {
  BIT_D1 = 0, BIT_D2, BIT_D3, BIT_D4, BIT_D5, BIT_D6, BIT_D7, BIT_D8, BIT_D9,
  BIT_D0,
  BIT_DOT_L,
  BIT_DOT_R,
  BIT_AN0, BIT_AN1, BIT_AN2, BIT_AN3
};

// 0..9 için katot bit maskesi (senin söylediğin mapping'e göre)
uint16_t katotMaskForDigit(uint8_t d) {
  switch (d) {
    case 0: return (1u << BIT_D0);
    case 1: return (1u << BIT_D1);
    case 2: return (1u << BIT_D2);
    case 3: return (1u << BIT_D3);
    case 4: return (1u << BIT_D4);
    case 5: return (1u << BIT_D5);
    case 6: return (1u << BIT_D6);
    case 7: return (1u << BIT_D7);
    case 8: return (1u << BIT_D8);
    case 9: return (1u << BIT_D9);
    default: return 0;
  }
}

// Lojik invert yardımcıları
inline uint16_t maybeInvertKatot(uint16_t m) { return INVERT_KATOT ? ~m : m; }
inline uint16_t maybeInvertAnot(uint16_t m)  { return INVERT_ANOT  ? ~m : m; }
inline uint16_t maybeInvertDot(uint16_t m)   { return INVERT_DOT   ? ~m : m; }

// 16-bit değeri 4094’lere (seri) kaydır: LSB-first
void shift16_LSBfirst(uint16_t value) {
  digitalWrite(PIN_LATCH, LOW);
  for (uint8_t i = 0; i < 16; i++) {
    digitalWrite(PIN_CLK, LOW);
    digitalWrite(PIN_DATA, (value >> i) & 0x1);
    digitalWrite(PIN_CLK, HIGH);
  }
  digitalWrite(PIN_LATCH, HIGH);
}

// Blanking kontrol (/OE: LOW=enable, HIGH=tri-state)
/*inline void outputsEnable(bool en) {
  digitalWrite(PIN_OE, en ? LOW : HIGH);
}*/

// Tek bir tüp için frame oluştur (katot + anot + noktalar)
uint16_t buildFrame(uint8_t digit, uint8_t tubeIndex, bool dotL, bool dotR) {
  uint16_t frame = 0;

  // Katot
  uint16_t k = katotMaskForDigit(digit);
  if (INVERT_KATOT) {
    // sadece katot bitlerini tersle
    uint16_t katotBits = 0;
    // katot bit alanı: 0..9
    for (uint8_t b = 0; b <= BIT_D0; b++) katotBits |= (1u << b);
    k = (~k) & katotBits;
  }
  frame |= k;

  // Noktalar (bit10, bit11)
  if (dotL ^ INVERT_DOT) frame |= (1u << BIT_DOT_L);
  if (dotR ^ INVERT_DOT) frame |= (1u << BIT_DOT_R);

  // Anot seçimi (bit12..15)
  uint16_t a = 0;
  switch (tubeIndex) {
    case 0: a = (1u << BIT_AN0); break;
    case 1: a = (1u << BIT_AN1); break;
    case 2: a = (1u << BIT_AN2); break;
    case 3: a = (1u << BIT_AN3); break;
  }
  if (INVERT_ANOT) {
    // sadece anot bitlerini tersle
    uint16_t anotBits = (1u << BIT_AN0) | (1u << BIT_AN1) | (1u << BIT_AN2) | (1u << BIT_AN3);
    a = (~a) & anotBits;
  }
  frame |= a;

  return frame;
}

// ========= Setup =========
void setup() {
  Serial.begin(115200);

  pinMode(PIN_DATA,  OUTPUT);
  pinMode(PIN_CLK,   OUTPUT);
  pinMode(PIN_LATCH, OUTPUT);
//  pinMode(PIN_OE,    OUTPUT);
 // outputsEnable(false); // Başta kapalı (tri-state)

  // WiFi
  WiFi.mode(WIFI_STA);
  WiFi.begin(ssid, password);
  uint32_t t0 = millis();
  while (WiFi.status() != WL_CONNECTED && millis() - t0 < 15000) {
    delay(300);
    Serial.print(".");
  }
  Serial.println(WiFi.status() == WL_CONNECTED ? "\nWiFi OK" : "\nWiFi FAIL");

  timeClient.begin();
  // TR sabit UTC+3, ek işlem yok
}

// HH:MM’yi 4 digit diziye ayır
void getTimeDigits(int d[4], bool &dotBlink) {
  timeClient.update();

  int h = timeClient.getHours();
  int m = timeClient.getMinutes();
  int s = timeClient.getSeconds();

  d[0] = (h / 10) % 10;
  d[1] =  h % 10;
  d[2] = (m / 10) % 10;
  d[3] =  m % 10;

  dotBlink = (s % 2 == 0); // 1 Hz yanıp sönme
}

// ========= Loop =========
void loop() {
  int digits[4];
  bool dots;
  getTimeDigits(digits, dots);

  // 4 tüpü sırayla göster
  for (uint8_t t = 0; t < 4; t++) {
    // tüpler arası ghosting’i önle: önce çıkışları kapat
   // outputsEnable(false);

    // noktalar: ortadaki iki tüp arasına gelecekse sağ/sol kullanımı
    bool dotL = (t == 1) ? dots : false; // 2. tüp sağında nokta (HH:MM görünümü için)
    bool dotR = (t == 2) ? dots : false; // 3. tüp solunda nokta

    uint16_t frame = buildFrame(digits[t], t, dotL, dotR);

    // yeni frame'i kaydır ve latch'le
    shift16_LSBfirst(frame);

    // aktif et ve belirlenen süre açık tut
   // outputsEnable(true);
    delayMicroseconds(ON_US_PER_TUBE);
  }
}

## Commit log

2025-02-23 Added Project Files V1.1
    [nixiesurucu2layer - CADCAM Bottom Assembly.GBR, nixiesurucu2layer - CADCAM Bottom Copper.GBR, nixiesurucu2layer - CADCAM Bottom Silk Screen.GBR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]
2025-03-02 Added outer case design of V2 model
    Added Stl and pdf files
    [nixiecasev2.STL]
2025-08-30 V4 Nixie Clock Driver with ESP8266 Wifi
2025-11-19 Add power supply and driver schematics
    Added PNG and PDF files for the power supply and driver schematics to the repository.
2025-11-21 Update power supply and driver schematics
    Revised the PNG and PDF files for the power supply and driver schematics to reflect recent design changes.
2025-11-21 Remove V2 and V4 hardware and firmware files
    Deleted images, schematics, CAD files, documentation, and the ESP8266 firmware for both V2 and V4 nixie projects. This cleanup removes obsolete or unnecessary project artifacts from the repository.
    [nixiecasev2.STL]
2025-11-21 Add V5.1 Nixie clock files and clean up V5 assets
    Added new V5.1 images, schematic, and source files for the Nixie clock. Removed obsolete V5 screenshots, documentation, CADCAM ZIPs, and schematic to streamline the project and reflect the latest har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
2025-11-25 Add schematics and PCB images for HV power supply
    Added PNG images for 3D view, PCB layout, and schematic of the 12V HV V1.2 board, as well as a PDF schematic for the HV power supply. These files provide visual documentation for hardware design and 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
2025-12-02 Organize V5.1 assets and add new design files
    Renamed existing V5.1 images and schematics into subfolders for better organization. Added new design files for v5-2, including 3D models, PCB images, schematics, and CAD files. Included a note in RM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
    [alt-parca.SLDPRT, ust-parca.SLDPRT]
2025-12-02 Rename HV Power Supply image files for consistency
    Renamed three image files to correct the directory name from 'HV Power pupply' to 'HV-Power-Supply' for improved consistency and clarity.
2025-12-02 Add HV Supply schematic image to README
    Added schematic image for HV Power Supply in README.
2025-12-27 Add V5.1 PCB image and update README
    Added 5.1_PCB_Image.jpeg to the V5.1 directory and updated the README to include the new PCB image in the V5 Photos section.
2025-12-27 Fix image paths and comment out duplicate images in README
    Corrected the file extension for a PCB image and commented out duplicate HV supply images with incorrect paths. Updated image links to ensure proper display in the documentation.
2025-12-27 Add V6 hardware revision notes to README
    Documented changes for hardware revision V6, including power supply modifications, EMC improvements, component updates, and layout adjustments. Added specific notes for the HV converter and recommend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
2025-12-27 Add V6 PCB and 3D images to documentation
    Updated README.md to include images for the V6 Nixie Clock PCB and 3D render. Added the corresponding image files in the V6 directory.
2025-12-30 Add new PCB images and update README references
    Added 5.1_PCB_Image-2.jpeg and 5.1_PCB_Image-3.jpeg to the V5.1 directory. Updated the README to reference the new images in the V5 Photos section.
2026-01-12 Comment out output enable pin and related logic
    The /OE (output enable) pin definition and all related logic have been commented out in the firmware. This change disables blanking control, possibly for hardware compatibility or debugging purposes.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
2026-01-12 Update README to reflect ESP8266 changes
    Removed outdated references to RTC and RS485 features, updated repository clone URL, and revised feature and requirements sections to match the current ESP8266-based design. Cleaned up to-do list and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
2026-05-16 Add V6 app image and README entry
    Add new image asset V6/v4.png and update README.md to include it as the 'V5.2 App Image' in the documentation image list, embedding the app screenshot alongside existing 3D/PCB/schematic images.
2026-05-26 Add V6 and V6-VFD images; update README
    Add new V6 assets and V6-VFD images, add IN-16 tube test image, and move v4.png into V5.1. Update README to reference the V5.1 app image, add a V6 app image and include the V6-VFD test image. Files a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
2026-07-24 Add V6.1.0 VFD UI image and reorganize docs
    Added new V6.1.0-VFD-UI-Image.png to the V6 VFD documentation section. Reorganized the V6 VFD gallery in README.md to include references to UI, PCB, and 3D images. Updated alt text for clarity and im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
2026-07-24 Add Community and Professional editions
    Reorganize repository into Community and Professional editions: move many V5.1 assets into V5.1-Community-Edition and V6/V6-VFD assets into Professional-Edition folders. Update README.md to use new i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
    [alt-parca.SLDPRT, ust-parca.SLDPRT]
2026-07-24 Add English README and language selector
    Add a full English README (README.en.md) and update the Turkish README (README.md) to include a language selector at the top. README.en.md provides an English translation of project info, features, installation, gallery and version notes. README.md received heading adjustments, the same language links, and minor copy fixes. This enables bilingual documentation and quick switching between English and Turkish.
2026-07-24 Update README: V6 notes, images, and clone link
    Adjust README.en.md and README.md: fix git clone link formatting, update image paths to the Professional-Edition folder, expand V6 / VFD support notes and add a new V6 Notes section (features, protection, enclosure/UI changes, stability and safety improvements), and update checklist statuses/add new TODO items. Changes apply to both English and Turkish READMEs.
